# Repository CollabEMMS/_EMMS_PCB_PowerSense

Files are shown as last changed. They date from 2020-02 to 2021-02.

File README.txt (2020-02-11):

README.txt
Power Sense v3.1.2
@author: Joe Wambach
@LastEditor: Joe Wambach		<----------------------- UPDATE THIS WHOEVER LAST EDITS THIS

last edit to this document: 2/21/19

Revision History:

	3.0:	Initial version of new power sense
	3.1: 	Removed Murata Transformer
		Removed R1
		Added Test Headers for CH0+, CH1+, HFout, Fout0, Fout1
		Added Triad Transformer
		Added Resistor Divider to bypass transformer circuitry
	3.1.1:	Changed connection for test header from CH1+ to CH1-
		R5 --> 20k 1%
	3.1.2:	Removed R15 and R16
		Fixed Connection to +5V on SPI Connector

Edits to be made in the future:
	- Fix issue with test header for CH1. Either flip connections to filters so CH1- is connected to GND. OR just change the connection for the test header from CH1+ to CH1-.
		DONE

	⁃ Fix circuitry so that resistor divider (bypassing transformer) and resistor divider (on transformer secondary) don’t connect and interfere with each other. OR just develop a good method to assemble boards with only one set of resistors or the other.

	⁃ Change resistor values on transformer secondary. It currently uses 10k and 1k to scale down by 11. This works for 120Vrms since transformer will output about 6Vp so MCP will get ~600mV. However, if 240Vrms connect to primary coils, 12Vp comes out of secondary meaning MCP will see 1.2Vp which is > 660mV maximum rating.
		DONE

	- Fix silkscreen part numbers and values

	- Fix trace connection to +5V of SPI because it barely touches it 
		DONE
	
	- Get rid of R16 and R15 because they prevent communication from working
		DONE

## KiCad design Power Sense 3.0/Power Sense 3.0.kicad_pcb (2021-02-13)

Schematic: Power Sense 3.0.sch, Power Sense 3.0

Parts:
C1, C2, C3, C4, C5, C6, C10: 100nF; C_Disc_D3.0mm_W1.6mm_P2.50mm
C7: 4.7uF; C_Disc_D3.0mm_W1.6mm_P2.50mm
C8, C9: 27pF; C_Disc_D3.0mm_W1.6mm_P2.50mm
D1, D2, D3: LED; LED_D5.0mm
IC1: MCP3909; mcp3909-i&slash_ss
J1: Power; Pin_Header_Straight_1x02_Pitch2.54mm
J2: ProgHead; Pin_Header_Straight_1x05_Pitch2.54mm
J3: SPI; PinHeader_1x07_P2.54mm_Vertical
J4: TestHeader; PinHeader_1x06_P2.54mm_Vertical
R1: 536k; R_Axial_DIN0204_L3.6mm_D1.6mm_P7.62mm_Horizontal
R2, R3: 10 1%; R_Axial_DIN0204_L3.6mm_D1.6mm_P7.62mm_Horizontal
R4, R6, R7, R8, R9, R12, R17, R18, R19, R21: 1k; R_Axial_DIN0204_L3.6mm_D1.6mm_P7.62mm_Horizontal
R5: 20k 1%; R_Axial_DIN0204_L3.6mm_D1.6mm_P7.62mm_Horizontal
R10, R22, R23: 330; R_Axial_DIN0204_L3.6mm_D1.6mm_P7.62mm_Horizontal
R11, R14: 10; R_Axial_DIN0204_L3.6mm_D1.6mm_P7.62mm_Horizontal
R13: 10k; R_Axial_DIN0204_L3.6mm_D1.6mm_P7.62mm_Horizontal
R20, R24: 0; R_Axial_DIN0204_L3.6mm_D1.6mm_P7.62mm_Horizontal
T1: AC1030
T2: 2p2sTransformer; Transformer FS12-090-C2
U1: PIC18F25K20_I/SS; PIC18F25K22-I_SP
Y1: 3.579545MHz Crystal; CXO_3_579545_MHz

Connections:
/5V_PULL_UP: J2.1, R13.2, U1.1
/+5V: C7.2, J2.2, J3.5, R11.2, R13.1, R14.2
/+12V: J3.7
/CH0+: C1.2, IC1.5, J4.5, R6.2
/CH1+: C4.1, IC1.8, R9.2
/CH1-: C3.2, IC1.7, J4.4, R8.2
/CHIP_SELECT: J3.4, U1.21
/Fo0toPIC: IC1.24, J4.1, U1.4
/Fo1toPIC: IC1.23, J4.2, U1.6
/H: J1.1, R20.2, T2.1
/HFtoPIC: IC1.22, J4.3, U1.5
/LED_TO_11: R22.2, U1.11
/LED_TO_12: R23.2, U1.12
/LED_TO_25: R10.2, U1.25
/MCLR: IC1.9, U1.17
/MCP_CS_TO_PIC: IC1.14, R21.1
/N: J1.2, R24.2, T2.4
/PROG_CLK: J2.4, U1.28
/PROG_DI: J2.5, U1.27
/SCK: IC1.12, R17.1
/SDI: IC1.13, R18.1
/SDO: IC1.20, R19.1
/SPI_CLK: J3.3, U1.22
/SPI_MD_IN: J3.1, U1.24
/SPI_MD_OUT: J3.2, U1.23
GND: C1.1, C2.2, C3.1, C4.2, C5.2, C6.1, C7.1, C8.2, C9.2, C10.2, D1.1 (K), D2.1 (K), D3.1 (K), IC1.11, IC1.15, IC1.16, IC1.21, J2.3, J3.6, J4.6, R2.2, R3.1, R4.1, R9.1, R12.1, R24.1, T2.6, U1.8, U1.19
unnamed: C2.1, IC1.6, R7.2
unnamed: C5.1, IC1.10
unnamed: C6.2, IC1.1, IC1.2, IC1.3, R11.1
unnamed: C8.1, IC1.18, Y1.1
unnamed: C9.1, IC1.17, Y1.2
unnamed: C10.1, R14.1, U1.20
unnamed: D1.2 (A), R10.1
unnamed: D2.2 (A), R22.1
unnamed: D3.2 (A), R23.1
unnamed: R1.1, R4.2, R5.1, R8.1, R12.2
unnamed: R1.2, R20.1
unnamed: R2.1, R6.1, T1.1
unnamed: R3.2, R7.1, T1.2
unnamed: R5.2, T2.5
unnamed: R17.2, U1.14
unnamed: R18.2, U1.15
unnamed: R19.2, U1.16
unnamed: R21.2, U1.18
unnamed: T2.2, T2.3

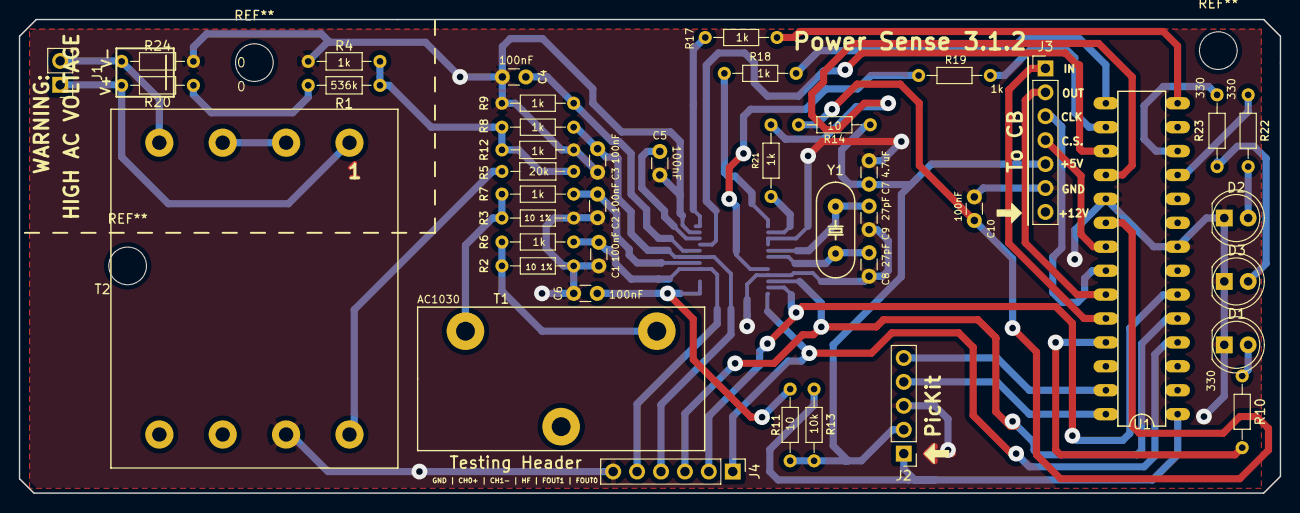
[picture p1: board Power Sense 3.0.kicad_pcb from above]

Board: 2 copper layers, 133.9 x 50.3 mm, 44 parts (1 on the bottom side), 44 nets.

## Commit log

2018-02-06 Initial Files
    [Current_Sense_Rev_2.2.brd, Current_Sense_Rev_2.2.sch]
2020-02-11 PS3.0 -> The right folder
    Moving things from where they were in the Power Sense 3.0 repository into the actual PCB_PowerSense repository
    [Current_Sense_Rev_2.2.brd, Current_Sense_Rev_2.2.sch, Power Sense 3.0-2018-11-27-13-07-39.sch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]
2021-02-13 Power Sense New Layout
    -- Moved Molex connector slot to match up (Not checked very well) to the command board.
    -- Need to Still double check the mounting holes!
    @Seth let's do a printout again but this time with adopted code
    [Power Sense 3.0.kicad_pcb]

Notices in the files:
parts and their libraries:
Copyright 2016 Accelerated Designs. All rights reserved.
